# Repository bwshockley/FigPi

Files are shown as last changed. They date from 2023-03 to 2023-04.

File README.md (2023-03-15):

# FigPi
Minifigure sized RP2040 based development board.

This has not been tested.  I have ordered prototype boards, so if you use this repo, please be prepared to have things not work.

## Board Definition for CircuitPython
[Fig Pi Board Definition - Local](https://github.com/bwshockley/circuitpython/tree/bwshockley-figpi/ports/raspberrypi/boards/bwshockley_figpi)

TODO: Once this board definition is pulled into the Adafruit repo, change link to the Adafruit repo.

## Changelog
**v1.1**
* Attached USB_BOOT to GPIO20, Pin 31
* Moved C12 to make room for new signal.

**v1.5**
* Changed all JST connectors to 4-pin.
* Moved SWDIO and SWCLK to test pads.
* Added APA102-2020 LEDs to make a 3 x 3 matrix.

**v1.6**
* Minor cosmetic changes to accomidate 'Status' label.

**v1.7**
* Fixed potential manufacturing limitation with ground vias.

**v2.1**
* Significant layout change to fix errors, move to mostly 0402 size passives, DFM, and more.

**v2.2**
* Updated the stemma connectors (i2c).  Pins were swapped - fixed the order.

**v2.3**
* Minor updates to routing, cleanup of vias, additional DRC checks.  Added silkscreen details.

**v2.3.1**
* Modified the silkscreen label from QWIIC0 and QWIIC1 to I2C0 and I2C1

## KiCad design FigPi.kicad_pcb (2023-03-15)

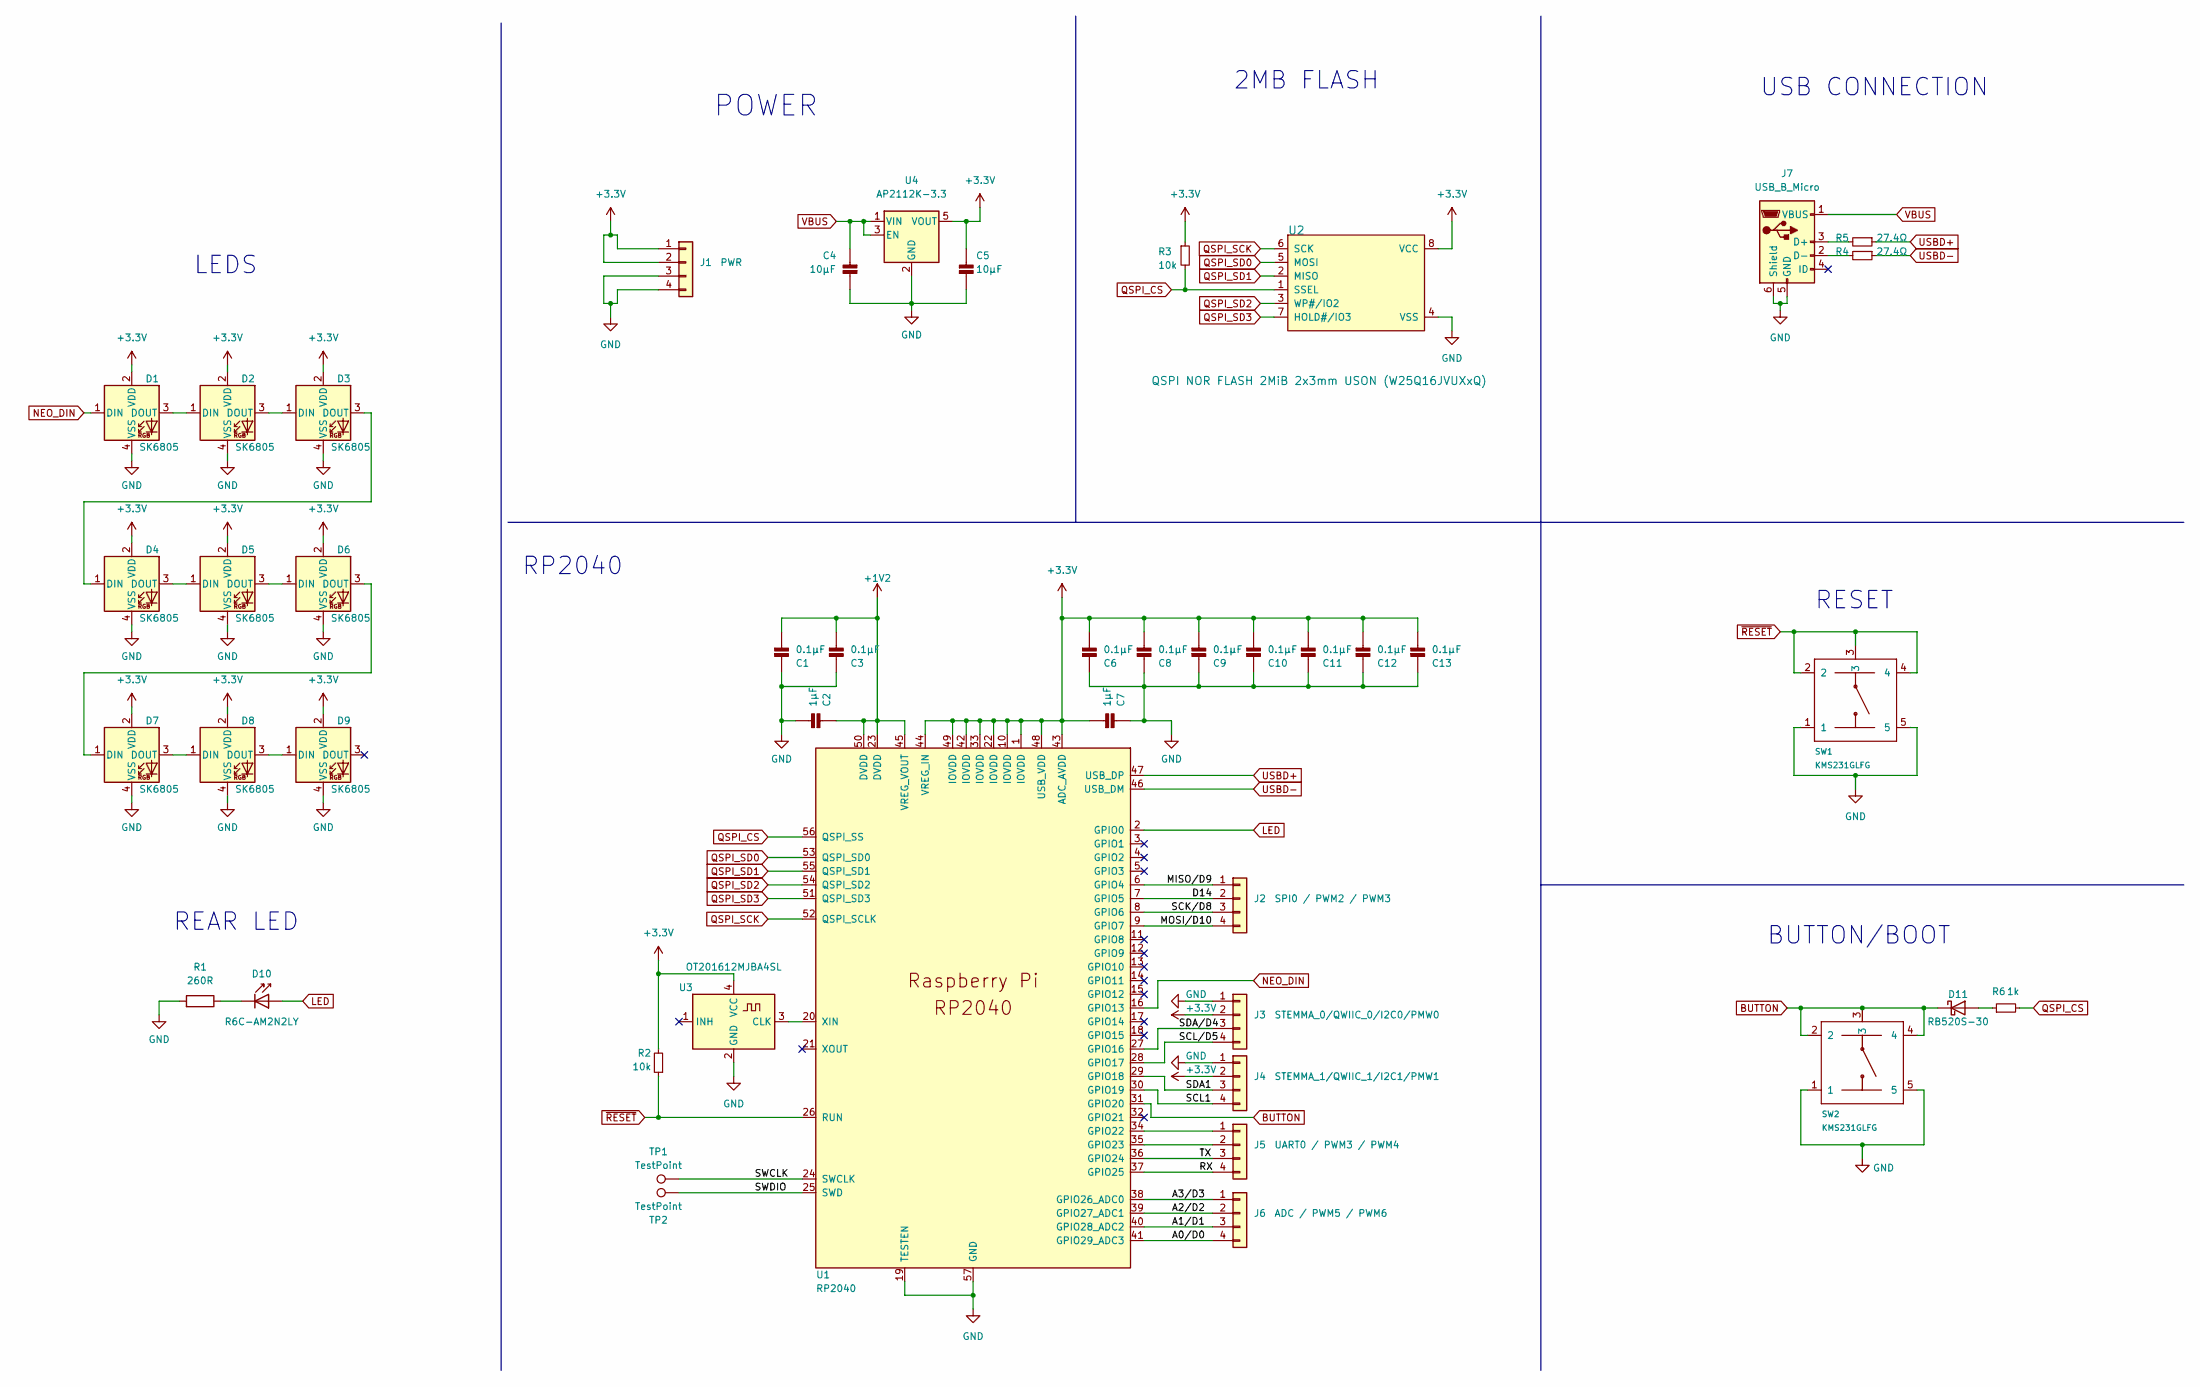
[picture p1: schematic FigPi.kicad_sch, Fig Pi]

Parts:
C1, C3, C6, C8, C9, C10, C11, C12, C13: 0.1µF; C_0402_1005Metric; JLCPCB C105882
C2, C7: 1µF; C_0402_1005Metric; JLCPCB C52923
C4, C5: 10µF; R_0603_1608Metric; JLCPCB C85713
D1, D2, D3, D4, D5, D6, D7, D8, D9: SK6805; LED_SK6805_EC15_1.5x1.5mm; JLCPCB C2890035
D10: R6C-AM2N2LY; LED_1.1x1.7mm; JLCPCB C605457
D11: RB520S-30; D_SOD-523; JLCPCB C8522
J1: PWR; JST_SH_SM04B-SRSS-TB_1x04-1MP_P1.00mm_Horizontal; JLCPCB C160404
J2: SPI0 / PWM2 / PWM3; JST_SH_SM04B-SRSS-TB_1x04-1MP_P1.00mm_Horizontal; JLCPCB C160404
J3: STEMMA_0/QWIIC_0/I2C0/PMW0; JST_SH_SM04B-SRSS-TB_1x04-1MP_P1.00mm_Horizontal; JLCPCB C160404
J4: STEMMA_1/QWIIC_1/I2C1/PMW1; JST_SH_SM04B-SRSS-TB_1x04-1MP_P1.00mm_Horizontal; JLCPCB C160404
J5: UART0 / PWM3 / PWM4; JST_SH_SM04B-SRSS-TB_1x04-1MP_P1.00mm_Horizontal; JLCPCB C160404
J6: ADC / PWM5 / PWM6; JST_SH_SM04B-SRSS-TB_1x04-1MP_P1.00mm_Horizontal; JLCPCB C160404
J7: USB_B_Micro; USB_Micro-B_Molex_47346-0001
R1: 260R; R_0603_1608Metric; JLCPCB C227740
R2, R3: 10k; R_0402_1005Metric; JLCPCB C144731
R4, R5: 27.4Ω; R_0402_1005Metric; JLCPCB C274349
R6: 1k; R_0402_1005Metric; JLCPCB C105637
SW1, SW2: KMS231GLFG; KMS_SWITCH; JLCPCB C221701
TP1, TP2: TestPoint; TestPoint_Pad_D1.0mm
U1: RP2040; QFN-56-1EP_7x7mm_P0.4mm_EP3.2x3.2mm; JLCPCB C2040
U2: QSPI NOR FLASH 2MiB 2x3mm USON (W25Q16JVUXxQ); USON-8_L3.0-W2.0-P0.50-BL-EP; JLCPCB C2843335
U3: OT201612MJBA4SL; Oscillator_SMD_Yangzing_Tech_SMD2016-4P; JLCPCB P/N C669076
U4: AP2112K-3.3; SOT-23-5; JLCPCB C3021085

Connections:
+1V2: C1.2, C2.1, C3.2, U1.23 (DVDD), U1.45 (VREG_VOUT), U1.50 (DVDD)
+3.3V: C5.1, C6.2, C7.2, C8.2, C9.2, C10.2, C11.2, C12.2, C13.2, D1.2 (VDD), D2.2 (VDD), D3.2 (VDD), D4.2 (VDD), D5.2 (VDD), D6.2 (VDD), D7.2 (VDD), D8.2 (VDD), D9.2 (VDD), J1.1, J1.2, J3.2, J4.2, R2.2, R3.1, U1.1 (IOVDD), U1.10 (IOVDD), U1.22 (IOVDD), U1.33 (IOVDD), U1.42 (IOVDD), U1.43 (ADC_AVDD), U1.44 (VREG_IN), U1.48 (USB_VDD), U1.49 (IOVDD), U2.8 (VCC), U3.4 (VCC), U4.5 (VOUT)
/A0/D0: J6.4, U1.41 (GPIO29_ADC3)
/A1/D1: J6.3, U1.40 (GPIO28_ADC2)
/A2/D2: J6.2, U1.39 (GPIO27_ADC1)
/A3/D3: J6.1, U1.38 (GPIO26_ADC0)
/D14: J2.2, U1.7 (GPIO5)
/MISO/D9: J2.1, U1.6 (GPIO4)
/MOSI/D10: J2.4, U1.9 (GPIO7)
/RX: J5.4, U1.37 (GPIO25)
/SCK/D8: J2.3, U1.8 (GPIO6)
/SCL1: J4.4, U1.30 (GPIO19)
/SCL/D5: J3.4, U1.28 (GPIO17)
/SDA1: J4.3, U1.29 (GPIO18)
/SDA/D4: J3.3, U1.27 (GPIO16)
/SWCLK: TP1.1, U1.24 (SWCLK)
/SWDIO: TP2.1, U1.25 (SWD)
/TX: J5.3, U1.36 (GPIO24)
BUTTON: D11.1 (K), SW2.2, SW2.3, SW2.4, U1.31 (GPIO20)
GND: C1.1, C2.2, C3.1, C4.1, C5.2, C6.1, C7.1, C8.1, C9.1, C10.1, C11.1, C12.1, C13.1, D1.4 (VSS), D2.4 (VSS), D3.4 (VSS), D4.4 (VSS), D5.4 (VSS), D6.4 (VSS), D7.4 (VSS), D8.4 (VSS), D9.4 (VSS), J1.3, J1.4, J3.1, J4.1, J7.5 (GND), J7.6 (Shield), R1.2, SW1.1, SW1.5, SW2.1, SW2.5, U1.19 (TESTEN), U1.57 (GND), U2.4 (VSS), U3.2 (GND), U4.2 (GND)
LED: D10.2 (A), U1.2 (GPIO0)
NEO_DIN: D1.1 (DIN), U1.16 (GPIO13)
unnamed: D1.3 (DOUT), D2.1 (DIN)
unnamed: D2.3 (DOUT), D3.1 (DIN)
unnamed: D3.3 (DOUT), D4.1 (DIN)
unnamed: D4.3 (DOUT), D5.1 (DIN)
unnamed: D5.3 (DOUT), D6.1 (DIN)
unnamed: D6.3 (DOUT), D7.1 (DIN)
unnamed: D7.3 (DOUT), D8.1 (DIN)
unnamed: D8.3 (DOUT), D9.1 (DIN)
unnamed: D10.1 (C), R1.1
unnamed: D11.2 (A), R6.1
unnamed: J5.1, U1.34 (GPIO22)
unnamed: J5.2, U1.35 (GPIO23)
unnamed: J7.2 (D-), R4.2
unnamed: J7.3 (D+), R5.2
unnamed: U1.20 (XIN), U3.3 (CLK)
QSPI_CS: R3.2, R6.2, U1.56 (QSPI_SS), U2.1 (SSEL)
QSPI_SCK: U1.52 (QSPI_SCLK), U2.6 (SCK)
QSPI_SD0: U1.53 (QSPI_SD0), U2.5 (MOSI)
QSPI_SD1: U1.55 (QSPI_SD1), U2.2 (MISO)
QSPI_SD2: U1.54 (QSPI_SD2), U2.3 (WP#/IO2)
QSPI_SD3: U1.51 (QSPI_SD3), U2.7 (HOLD#/IO3)
USBD+: R5.1, U1.47 (USB_DP)
USBD-: R4.1, U1.46 (USB_DM)
VBUS: C4.2, J7.1 (VBUS), U4.1 (VIN), U4.3 (EN)
~RESET: R2.1, SW1.2, SW1.3, SW1.4, U1.26 (RUN)

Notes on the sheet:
REAR LED
2MB FLASH
RESET
POWER
BUTTON/BOOT
USB CONNECTION
LEDS
RP2040

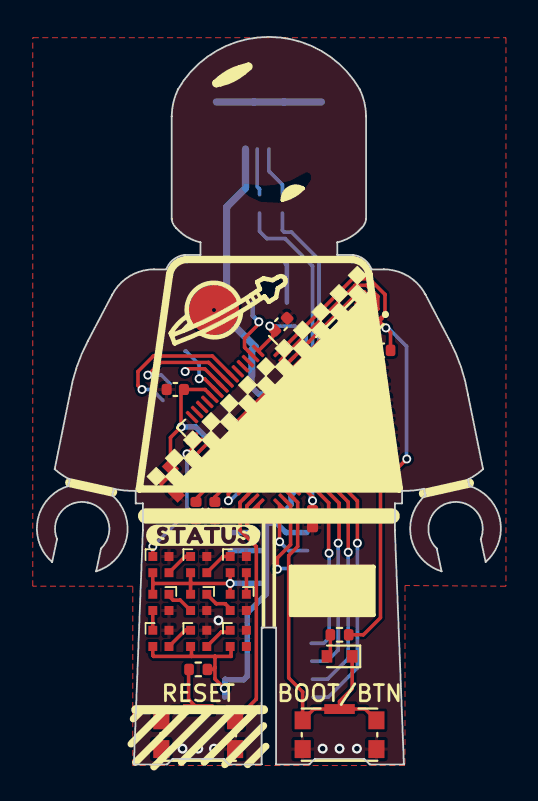
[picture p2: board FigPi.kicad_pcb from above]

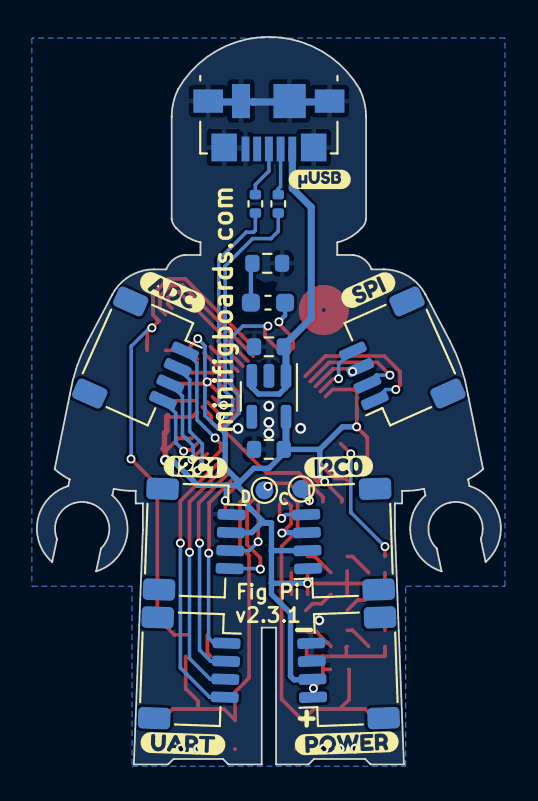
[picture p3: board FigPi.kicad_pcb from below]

Board: 2 copper layers, 25.8 x 40.4 mm, 53 parts (23 on the bottom side), 47 nets.

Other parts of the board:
kibuzzard-640B746F: G***; kibuzzard-640B746F
kibuzzard-640F7BF6: G***; kibuzzard-640F7BF6
kibuzzard-640F7C1A: G***; kibuzzard-640F7C1A
kibuzzard-640F7C6F: G***; kibuzzard-640F7C6F
kibuzzard-640F7C7F: G***; kibuzzard-640F7C7F
kibuzzard-640F7D7C: G***; kibuzzard-640F7D7C
kibuzzard-6411F9C1: G***; kibuzzard-6411F9C1
kibuzzard-6411FA03: G***; kibuzzard-6411FA03

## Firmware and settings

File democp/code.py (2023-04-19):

import time
import board
import digitalio
import neopixel
from adafruit_led_animation.animation.pulse import Pulse
from adafruit_led_animation.sequence import AnimationSequence
from adafruit_led_animation.color import (
    PURPLE,
    WHITE,
    AMBER,
    JADE,
    TEAL,
    PINK,
    MAGENTA,
    ORANGE,
    RED,
)

pixel_pin = board.NEOPIXEL
led_back = digitalio.DigitalInOut(board.LED)
led_back.direction = digitalio.Direction.OUTPUT
button_1 = digitalio.DigitalInOut(board.BUTTON)
button_1.switch_to_input(pull=digitalio.Pull.DOWN)

# The number of NeoPixels
num_pixels = 9

# The order of the pixel colors - RGB or GRB. Some NeoPixels have red and green reversed!
# For RGBW NeoPixels, simply change the ORDER to RGBW or GRBW.
ORDER = neopixel.GRB

pixels = neopixel.NeoPixel(
    pixel_pin, num_pixels, brightness=0.5, auto_write=False, pixel_order=ORDER
)

pulse = Pulse(pixels, speed=.01, color=TEAL, period=0.75)


def wheel(pos):
    # Input a value 0 to 255 to get a color value.
    # The colours are a transition r - g - b - back to r.
    if pos < 0 or pos > 255:
        r = g = b = 0
    elif pos < 85:
        r = int(pos * 3)
        g = int(255 - pos * 3)
        b = 0
    elif pos < 170:
        pos -= 85
        r = int(255 - pos * 3)
        g = 0
        b = int(pos * 3)
    else:
        pos -= 170
        r = 0
        g = int(pos * 3)
        b = int(255 - pos * 3)
    return (r, g, b) if ORDER in (neopixel.RGB, neopixel.GRB) else (r, g, b, 0)


def rainbow_cycle(wait):
    for j in range(255):
        for i in range(num_pixels):
            pixel_index = (i * 256 // num_pixels) + j
            pixels[i] = wheel(pixel_index & 255)
        pixels.show()
        time.sleep(wait)

def heart_pulse(wait, pixint):
    pixels[0] = (pixint, 0, 0)
    pixels[1] = (0, 0, 0)
    pixels[2] = (pixint, 0, 0)
    pixels[3] = (pixint, 0, 0)
    pixels[4] = (pixint, 0, 0)
    pixels[5] = (pixint, 0, 0)
    pixels[6] = (0, 0, 0)
    pixels[7] = (pixint, 0, 0)
    pixels[8] = (0, 0, 0)
    pixels.show()
    time.sleep(wait)

animations = AnimationSequence(pulse)


while True:
    led_back.value = button_1.value
    rainbow_cycle(0.001)  # rainbow cycle with 1ms delay per step
    #animations.animate()

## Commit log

2022-07-20 Initial Add - V.10
    Adding the first files. Warning these have not been tested.
    [FigPi.kicad_pcb, FigPi.kicad_sch]
2022-07-20 Connected USBOOT properly to Boot button. Had to move capacitor for new track.
    [FigPi.kicad_pcb, FigPi.kicad_sch]
2022-07-21 v1.5 - Changed all JST connections to 4-pin. Added 8 additional APA102 - 2020 LEDs for a 3 x 3 matrix. Rearranged items as needed. Moved SWDIO and SWCLK from JST connector to test pads.
    [FigPi.kicad_pcb, FigPi.kicad_sch]
2022-07-21 1.6 - Minor Cosmetic Changes
    [FigPi.kicad_pcb, FigPi.kicad_sch]
2022-07-21 Update README.md
    CircuitPython board definition link.
2022-07-21 v1.7 Fixed potential manufacturing limitation with ground vias.
    [FigPi.kicad_pcb]
2023-03-01 Updated to Rev 2.1 - layout changes, smd size changes.
    [FigPi.kicad_pcb, FigPi.kicad_sch]
2023-03-10 modified: FigPi.kicad_pcb modified: FigPi.kicad_sch
    Swapped around the stemma connector pins.
    [FigPi.kicad_pcb, FigPi.kicad_sch]
2023-03-14 Update to v2.3
    Updated the schematic and board to v2.3.
    [FigPi.kicad_pcb, FigPi.kicad_sch]
2023-03-15 Updated Bottom Silkscreen
    Changed the I2C connector labels.
    [FigPi.kicad_pcb]
